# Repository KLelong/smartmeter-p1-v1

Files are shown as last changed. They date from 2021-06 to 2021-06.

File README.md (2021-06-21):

# smartmeter-p1-v1
Readout of a Flemish smartmeter via the P1 port and publish it to MQTT.
The meter uses the DSMR v5 protocol, so probably recent Dutch meters can be read out.

## Software

The software is intended to run on an ESP8266 device.
This version is made with the Arduino IDE.
The software is based on https://github.com/neographikal/P1-Meter-ESP8266-MQTT and others.

## Hardware

I made a motherboard containing a Wemos D1 mini R2 and the hardware to connect to the P1 port of the energy-meter. Later I swapped the mini R2 with a mini Pro, because the poor WiFi signal at my meter. So both can be used.

## Risk

Both software and hardware are running fine at my home. Using any of this is at your own risk.

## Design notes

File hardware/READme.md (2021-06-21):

The board is setup to be it's own housing.

The first prototype, so the board was not cleaned after soldering.


The device in action on the meter.
There is a lid, but the hole for the LED is not aligned. 
Also I didn't mount the switch because I didn't have a suitable type.
That switch is there to reset the device to "factory seetings".




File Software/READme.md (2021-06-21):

The software is configured to use a secure MQTT-server. The initial version used an unsecured server so modifying to use an unsecured MQTT-server is possible.

Initially you need to configure the WiFi-settings of the device : just power on (plug into meter), there will be an accesspoint named smartmeter-p1. You can connect to it using the password Koenraad (my first name ;-) )
When connected to the accesspoint, go to 192.168.4.1 and there you can setup the device to connect to your wifi network and set your own device-name.
The LED will blink fast to indicate the accesspoint is up.

After your device has made a connection to you wifi-network, the led will stay lit. Then you can go to the web-site of the device.
There are three pages on the web-site : the data page where you can see the data from the meter. A setup page where you can further configure the device. And an about page.
You can access the setup-page by using the initial user and password : admin and smartmeter-p1.
On the page you can configure various settings. Those become active after saving and restarting the device. Settings are stored in EEPROM, so these are safe from power-loss.
You also can upload new firmware.
If for some reason the device loses WiFi-connection, the LED will blink slowly and the device will reboot after some time to try to reconnect.

Please bear in mind that all web-trafic is unsecure (plain http). Passwords are NOT sent to your browser, but when changing passwords those are sent to the device in plain-text.
Another point to note : the meter uses the serial port of the ESP8266, so you can't connect the meter *and* upload software via USB. 
A final note : the P1-port needs to be activated by the provider, so plan ahead !

Enjoy.

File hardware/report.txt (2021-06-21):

Plot file "/home/koenraad/ownCloud/documents/devel/hardware/SlimmeMeter/slimme-meter/Gerber/slimme-meter-tra-F_Cu.gbr" created.
Plot file "/home/koenraad/ownCloud/documents/devel/hardware/SlimmeMeter/slimme-meter/Gerber/slimme-meter-tra-B_Cu.gbr" created.
Plot file "/home/koenraad/ownCloud/documents/devel/hardware/SlimmeMeter/slimme-meter/Gerber/slimme-meter-tra-F_Paste.gbr" created.
Plot file "/home/koenraad/ownCloud/documents/devel/hardware/SlimmeMeter/slimme-meter/Gerber/slimme-meter-tra-F_SilkS.gbr" created.
Plot file "/home/koenraad/ownCloud/documents/devel/hardware/SlimmeMeter/slimme-meter/Gerber/slimme-meter-tra-B_SilkS.gbr" created.
Plot file "/home/koenraad/ownCloud/documents/devel/hardware/SlimmeMeter/slimme-meter/Gerber/slimme-meter-tra-F_Mask.gbr" created.
Plot file "/home/koenraad/ownCloud/documents/devel/hardware/SlimmeMeter/slimme-meter/Gerber/slimme-meter-tra-B_Mask.gbr" created.
Plot file "/home/koenraad/ownCloud/documents/devel/hardware/SlimmeMeter/slimme-meter/Gerber/slimme-meter-tra-Edge_Cuts.gbr" created.
Create Gerber job file "/home/koenraad/ownCloud/documents/devel/hardware/SlimmeMeter/slimme-meter/Gerber/slimme-meter-tra-job.gbrjob"

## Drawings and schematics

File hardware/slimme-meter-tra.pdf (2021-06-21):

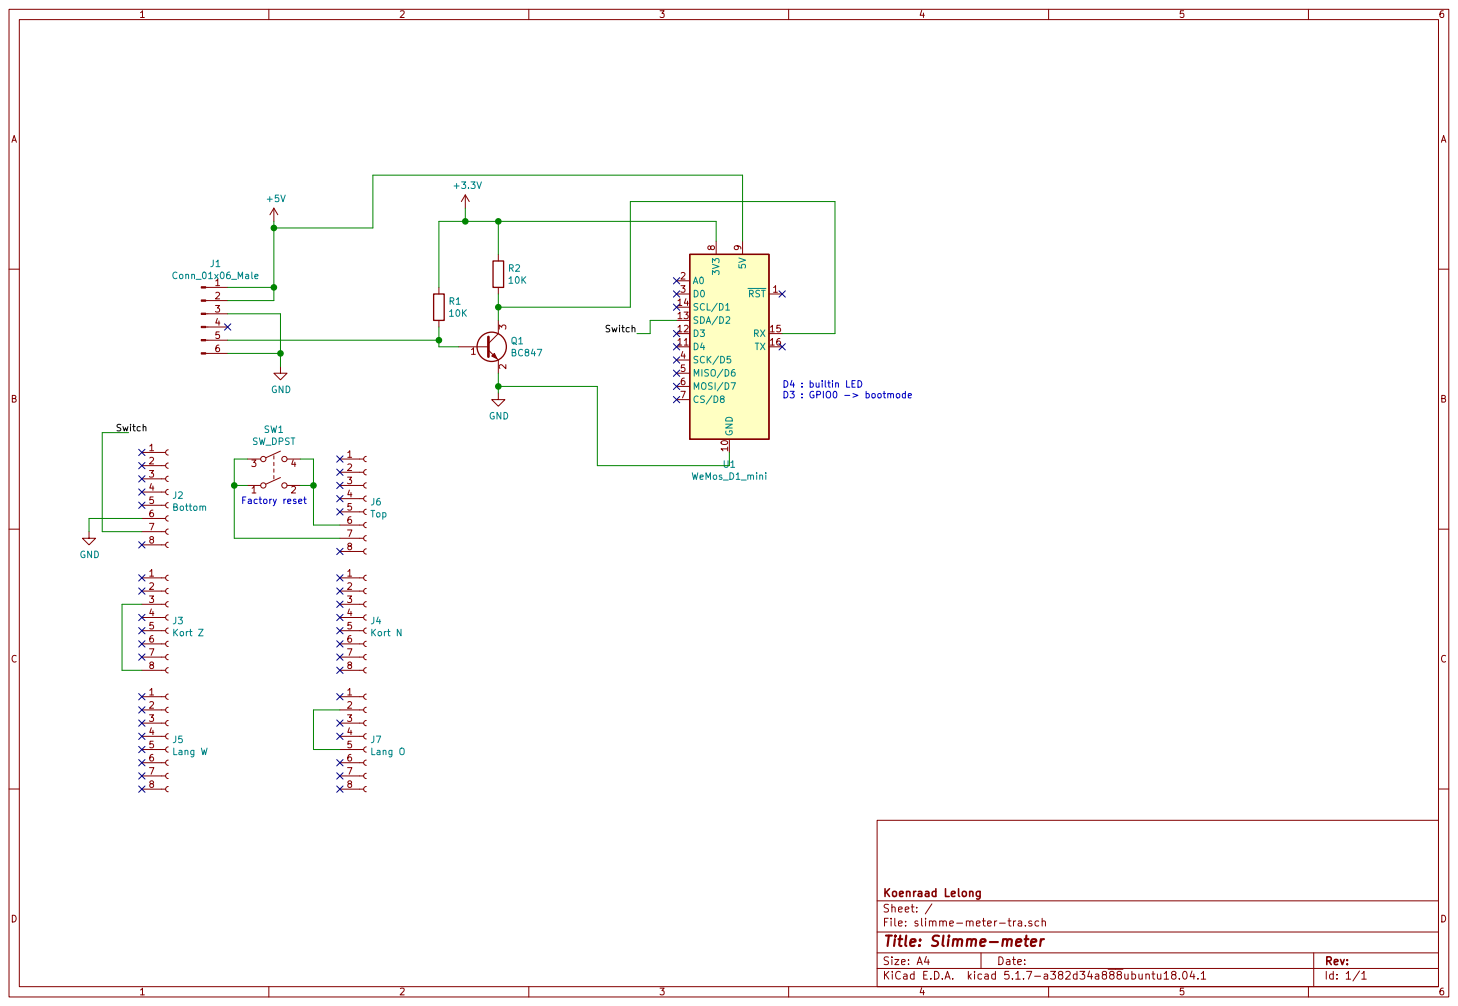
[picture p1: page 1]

Id: 1/1 Title: Slimme-meter File: slimme-meter-tra.sch Sheet: / Koenraad Lelong

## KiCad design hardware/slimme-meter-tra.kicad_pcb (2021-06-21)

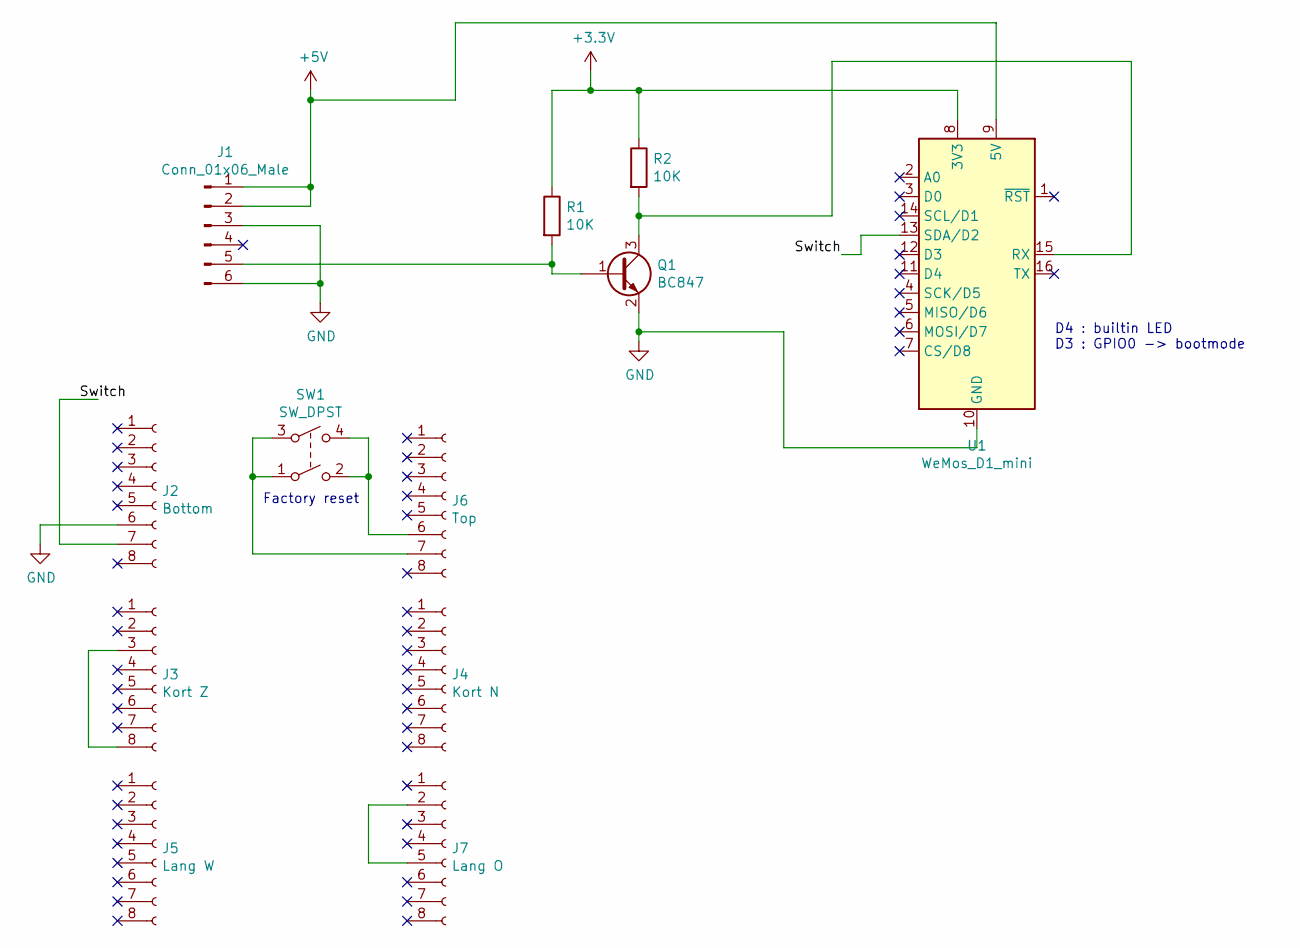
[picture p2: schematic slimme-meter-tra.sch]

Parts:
J1: Conn_01x06_Male; PinHeader_1x06_P2.54mm_Vertical_SMD_Pin1Right
J2: Bottom; bottom
J3: Kort Z; zij-kort
J4: Kort N; zij-lang
J5: Lang W; zij-kort
J6: Top; top
J7: Lang O; zij-lang
Q1: BC847; SOT-23
R1, R2: 10K; R_0805_2012Metric_Pad1.15x1.40mm_HandSolder
SW1: SW_DPST; SW_Push_2P2T_Vertical_E-Switch_800UDP8P1A1M6
U1: WeMos_D1_mini; wemos-mini-d1-SMT

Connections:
+3V3: R1.1, R2.1, U1.8 (3V3)
+5V: J1.1, J1.2, U1.9 (5V)
/Switch: J2.7, U1.13 (SDA/D2)
GND: J1.3, J1.6, J2.6, Q1.2 (E), U1.10 (GND)
unnamed: J1.5, Q1.1 (B), R1.2
unnamed: J3.3, J3.8
unnamed: J6.6, SW1.2, SW1.4
unnamed: J6.7, SW1.1, SW1.3
unnamed: J7.2, J7.5
unnamed: Q1.3 (C), R2.2, U1.15 (RX)

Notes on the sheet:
D4 : builtin LED D3 : GPIO0 -> bootmode
Factory reset

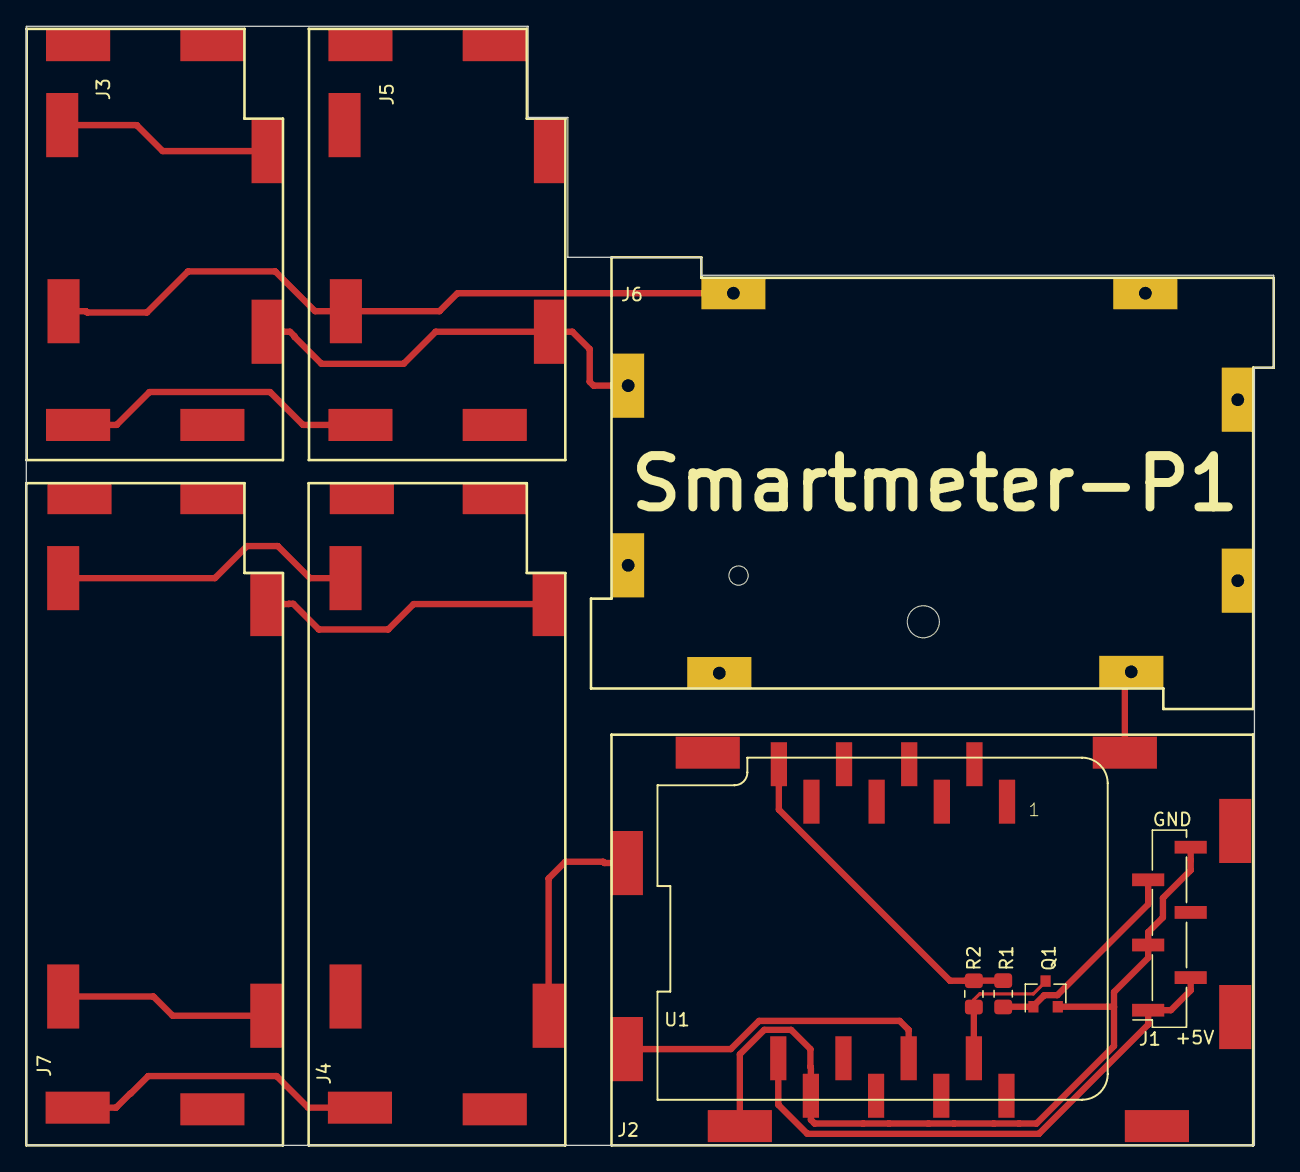
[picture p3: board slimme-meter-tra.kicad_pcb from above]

Board: 2 copper layers, 97.2 x 87.2 mm, 11 parts (0 on the bottom side), 8 nets.

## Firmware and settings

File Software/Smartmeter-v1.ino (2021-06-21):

/*
 * to do
 * MQTT : als host en user gelijk zijn aan een ander device : mqtt-connect in een eindeloze lus. Er voor zorgen dat setup kan 
 *        gebruikt worden (hoe ?).
 * MQTT : beveiliging of niet : bij definitie van fingerprint : beveiligde mqtt, anders niet. Twee WiFiClients, één secure, andere niet.
 * 
*/

/*
 * device = ESP8266 Wemos D1 R2 & mini  
*/

#include <ESP8266WiFi.h>          //https://github.com/esp8266/Arduino

//needed for library
#include <ESP8266mDNS.h>
//#include <DNSServer.h>
#include <ESP8266WebServer.h>
#include <WiFiManager.h>         //https://github.com/tzapu/WiFiManager
#include <ArduinoOTA.h>
#include <PubSubClient.h>
#include <EEPROM.h>
#include <Ticker.h>

#include "index_html.h"
#include "about_html.h"
#include "config_html.h"
#include "update_html.h"
#include "smartmeter_css.h"
#include "favicon_ico.h"

/*
 * Version
 */
const char* P1Version = "1.19a";

#define DEBUG0
//
// If we did then DEBUG_LOG will log a string, otherwise
// it will be ignored as a comment.
//
#ifdef DEBUG
#  define DEBUG_LOG(x) Serial.print(x)
#else
#  define DEBUG_LOG(x)
#endif

#define EEPROM_MAGIC 31415 // to test if EEPROM is valid
#define EEPROM_MAGIC_ADDR 0 // 2 bytes
#define HOSTNAME_ADDR EEPROM_MAGIC_ADDR+2 // 
#define HOSTNAME_LEN 33
#define MQTTSERVER_ADDR HOSTNAME_ADDR+HOSTNAME_LEN
#define MQTTSERVER_LEN 33
#define MQTTPASS_ADDR MQTTSERVER_ADDR+MQTTSERVER_LEN
#define MQTTPASS_LEN 33
#define MQTTPORT_ADDR MQTTPASS_ADDR+MQTTPASS_LEN
#define MQTTPORT_LEN 6
#define MQTTTOPIC_ADDR MQTTPORT_ADDR+MQTTPORT_LEN
#define MQTTTOPIC_LEN 33
#define MQTTCLIENT_ADDR MQTTTOPIC_ADDR+MQTTTOPIC_LEN
#define MQTTCLIENT_LEN 33
#define DELAY_ADDR MQTTCLIENT_ADDR+MQTTCLIENT_LEN
#define DELAY_LEN 7
#define OTAPASS_ADDR DELAY_ADDR+DELAY_LEN
#define OTAPASS_LEN 33
#define WWWUSER_ADDR OTAPASS_ADDR+OTAPASS_LEN
#define WWWUSER_LEN 33
#define WWWPASS_ADDR WWWUSER_ADDR+WWWUSER_LEN
#define WWWPASS_LEN 33
#define MQTTS_ADDR WWWPASS_ADDR+WWWPASS_LEN  //sha1-fingerprint of mqtt-server
#define MQTTS_LEN 60

IPAddress mqttServerIP;
WiFiManager wifiManager;
WiFiClientSecure espClientS;
PubSubClient sclient(espClientS);
ESP8266WebServer httpserver(80);

#define MAXLINELENGTH 64
char telegram[MAXLINELENGTH];

char hostName[HOSTNAME_LEN] = "smartmeter-p1";
char mqtt_server[MQTTSERVER_LEN] = "";
char mqtt_pass[MQTTPASS_LEN] = "";
char mqtt_port[MQTTPORT_LEN] = "1883";
char mqtt_client[MQTTCLIENT_LEN] = "smartmeter";
char mqtt_topic[MQTTTOPIC_LEN] = "energy/p1";
char OTAPassword[OTAPASS_LEN] = "";
char www_username[WWWUSER_LEN] = "admin";
char www_password[WWWPASS_LEN] = "smartmeter-p1";
char fingerprint[MQTTS_LEN];// = "xx:xx:xx:xx:xx:xx:xx:xx:xx:xx:xx:xx:xx:xx:xx:xx:xx:xx:xx:xx";
// allows you to set the realm of authentication Default:"Login Required"
const char* www_realm = "Setup smartmeter-p1";
// the Content of the HTML response in case of Unautherized Access Default:empty
String authFailResponse = "Authentication Failed";

char TopicSub[MQTTTOPIC_LEN];  //topic to subscribe to
char TopicPub[MQTTTOPIC_LEN];  //topic to publish to
String tempTopic;
String mqttP1TopicS;
int mqttP1TopicSLen;
String P1VersionStr;
#define VERSION_LEN 25
char P1VersionArr[VERSION_LEN];

const bool outputOnSerial = true;
bool resetReq = false;
bool initReq = false;
bool mqtt_server_def = false;

// Vars to store meter readings
long powerConsumptionDay = 0;      //Meter reading Electrics - consumption day tariff in watt hours
long powerConsumptionNight = 0;    //Meter reading Electrics - consumption night tariff  in watt hours
long powerProductionDay = 0;       //Meter reading Electrics - return day tariff  in watt hours
long powerProductionNight = 0;     //Meter reading Electrics - return night tariff  in watt hours
long CurrentPowerConsumption = 0;  //Meter reading Electrics - Actual consumption in watts
long CurrentPowerProduction = 0;   //Meter reading Electrics - Actual return in watts
float GasConsumption = 0.0;        //Meter reading Gas in m3

//Infrastructure stuff
int PublishDelay = 10;             // 10 P1 telegrams before update of values.  
int TelegramCount = 0;             // Counter for received telegrams
//flag for saving data of WiFi manager
bool shouldSaveConfig = false;

#include "sm-eeprom.h"
#include "sm-io.h"
#include "sm-wifi.h"
#include "sm-http.h"
#include "sm-mqtt.h"
#include "sm-OTA.h"
#include "sm-serial.h"

void setup() {
    // put your setup code here, to run once:
  Serial.begin(115200);
  Serial.println("Booting");
  Serial.print("smartmeter-p1");
  Serial.println(" on Wemos D1 Mini & R2");
  Serial.print("Version : ");
  Serial.println(P1Version);
  
  EEPROMsetup();
  ioSetup();
  WiFiManagersetup();
  OTAsetup();
  MQTTsetup();
  httpSetup();
}

void loop() {
    // put your main code here, to run repeatedly:
  
  if (mqtt_server_def) {
    if (!sclient.connected()) {
      reconnect();
    }
    else {
      sclient.loop();
    }
  }
  readTelegram();    
  ArduinoOTA.handle();
  httpserver.handleClient();
  ioLoop();
  if (resetReq || initReq) {
    if (initReq) {  // Factory defaults ?
     EEPROM.write(EEPROM_MAGIC_ADDR,0);
     EEPROM.commit();
     DEBUG_LOG("EEPROM cleared\n");
    }
    delay (1000);                                // Yes, wait some time
    ESP.restart();                               // Reboot
    delay (1000);                                // Yes, wait some time
  } 
  MDNS.update(); 
  wifiloop();
}

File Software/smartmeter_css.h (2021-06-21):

// smartmeter.css file in raw data format for PROGMEM
//
const char smartmeter_css[] PROGMEM = R"=====(
body {
   background-color: lightsalmon;
   font-family: Arial, Helvetica, sans-serif;
}

h1 {
   color: navy;
   margin-left: 20px;
   font-size: 150%
}

ul {
   list-style-type: none;
   margin: 0;
   margin-left: -10px;
   overflow: hidden;
   background-color: saddlebrown;
   position:fixed;
   top:0;
   width:100%;
   z-index:100;
}

li .pull-left {
   float: left;
}

li .pull-right {
   float: right;
}

li a {
   display: block;
   color: white;
   text-align: center;
   padding: 14px 16px;
   text-decoration: none;
}

li a:hover, a.active {
   background-color: #111;
}

td.config {
   text-align: right;
}

.button {
   width: 90px;
   height: 30px;
   background-color: #128F76;
   border: none;
   color: white;
   text-align: center;
   text-decoration: none;
   display: inline-block;
   font-size: 16px;
   margin: 4px 2px;
   cursor: pointer;
   border-radius: 10px;
}

.buttonr {background-color: red;}

.select {
   width: 160px;
   height: 32px;
   padding: 5px;
   background: white;
   font-size: 16px;
   line-height: 1;
   border: 1;
   border-radius: 5px;
   -webkit-border-radius: 5px;
   -moz-border-radius: 5px;
   -webkit-appearance: none;
   border: 1px solid black;
   border-radius: 10px;
}

.selectw {width: 410px;}

input {
   margin: 0;
   height: 28px;
   background: white;
   font-size: 16px;
   appearance: none;
   box-shadow: none;
   border-radius: 5px;
   -webkit-border-radius: 5px;
   -moz-border-radius: 5px;
   -webkit-appearance: none;
   border: 1px solid black;
   border-radius: 10px;
}

input[type="text"] {
   text-align: right;
}

input.config {
   text-align: left;
   width: 300px;
}

input.Version {
   text-align: center;
   border: 0px;
   background-color: transparent;
}

input[type="text"]:focus {
  outline: none;
}

input[type=submit] {
  width: 200px;
  height: 40px;
  background-color: #128F76;
  border: none;
  color: white;
  text-align: center;
  text-decoration: none;
  display: inline-block;
  font-size: 16px;
  margin: 4px 2px;
  cursor: pointer;
  border-radius: 5px;
}

textarea {
  width: 80;
  height: 25;
  border: 1px solid black;
  border-radius: 10px;
  padding: 5px;
  font-family: Courier, "Lucida Console", monospace;
  background-color: white;
  resize: none;
}
)=====" ;

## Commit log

2021-06-21 Initial hardware
    [slimme-meter-tra-B_Cu.gbr, slimme-meter-tra-B_Mask.gbr, slimme-meter-tra-B_SilkS.gbr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]
2021-06-21 Documentation updates to hardware
    [slimme-meter-tra.sch]
